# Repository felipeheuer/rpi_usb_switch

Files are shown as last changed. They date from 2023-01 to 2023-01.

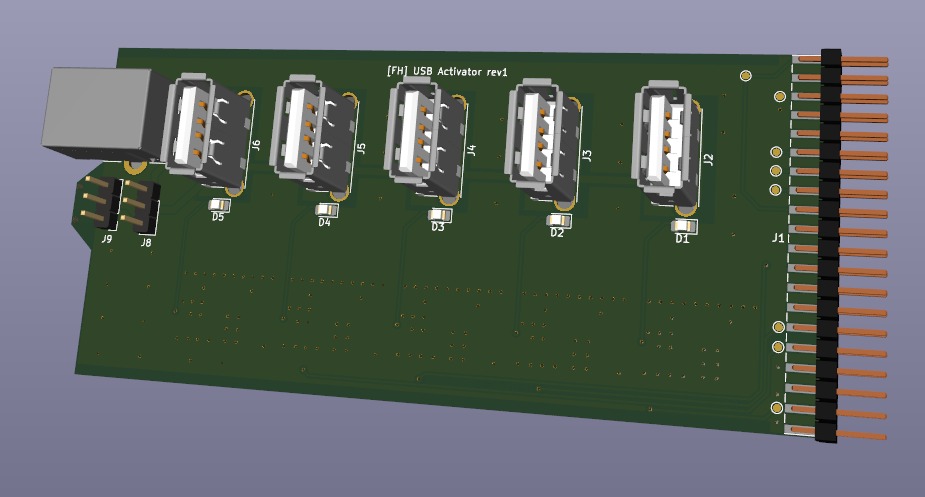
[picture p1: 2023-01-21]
img/board-rev1.jpeg

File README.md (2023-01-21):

# Raspberry Pi controlled USB switch

This is a simple project that allows you to enable/disable power lines from 5 USB ports individually over 5 GPIO's from a Raspberry Pi.

Was initially made to re-use an old dead USB hub that was laying down on my drawers an recycle it into a nice hub for powering up my LED gadgets.
The Mosfet circuitry layout is based on a generic circuit found on Amazon from different brands, but might have [this guy](https://michiel.vanderwulp.be/domotica/Modules/MosFetPwmDriveModule/) as a father.

**Data lines are disabled, this is only used for devices that have USB port as power source.**

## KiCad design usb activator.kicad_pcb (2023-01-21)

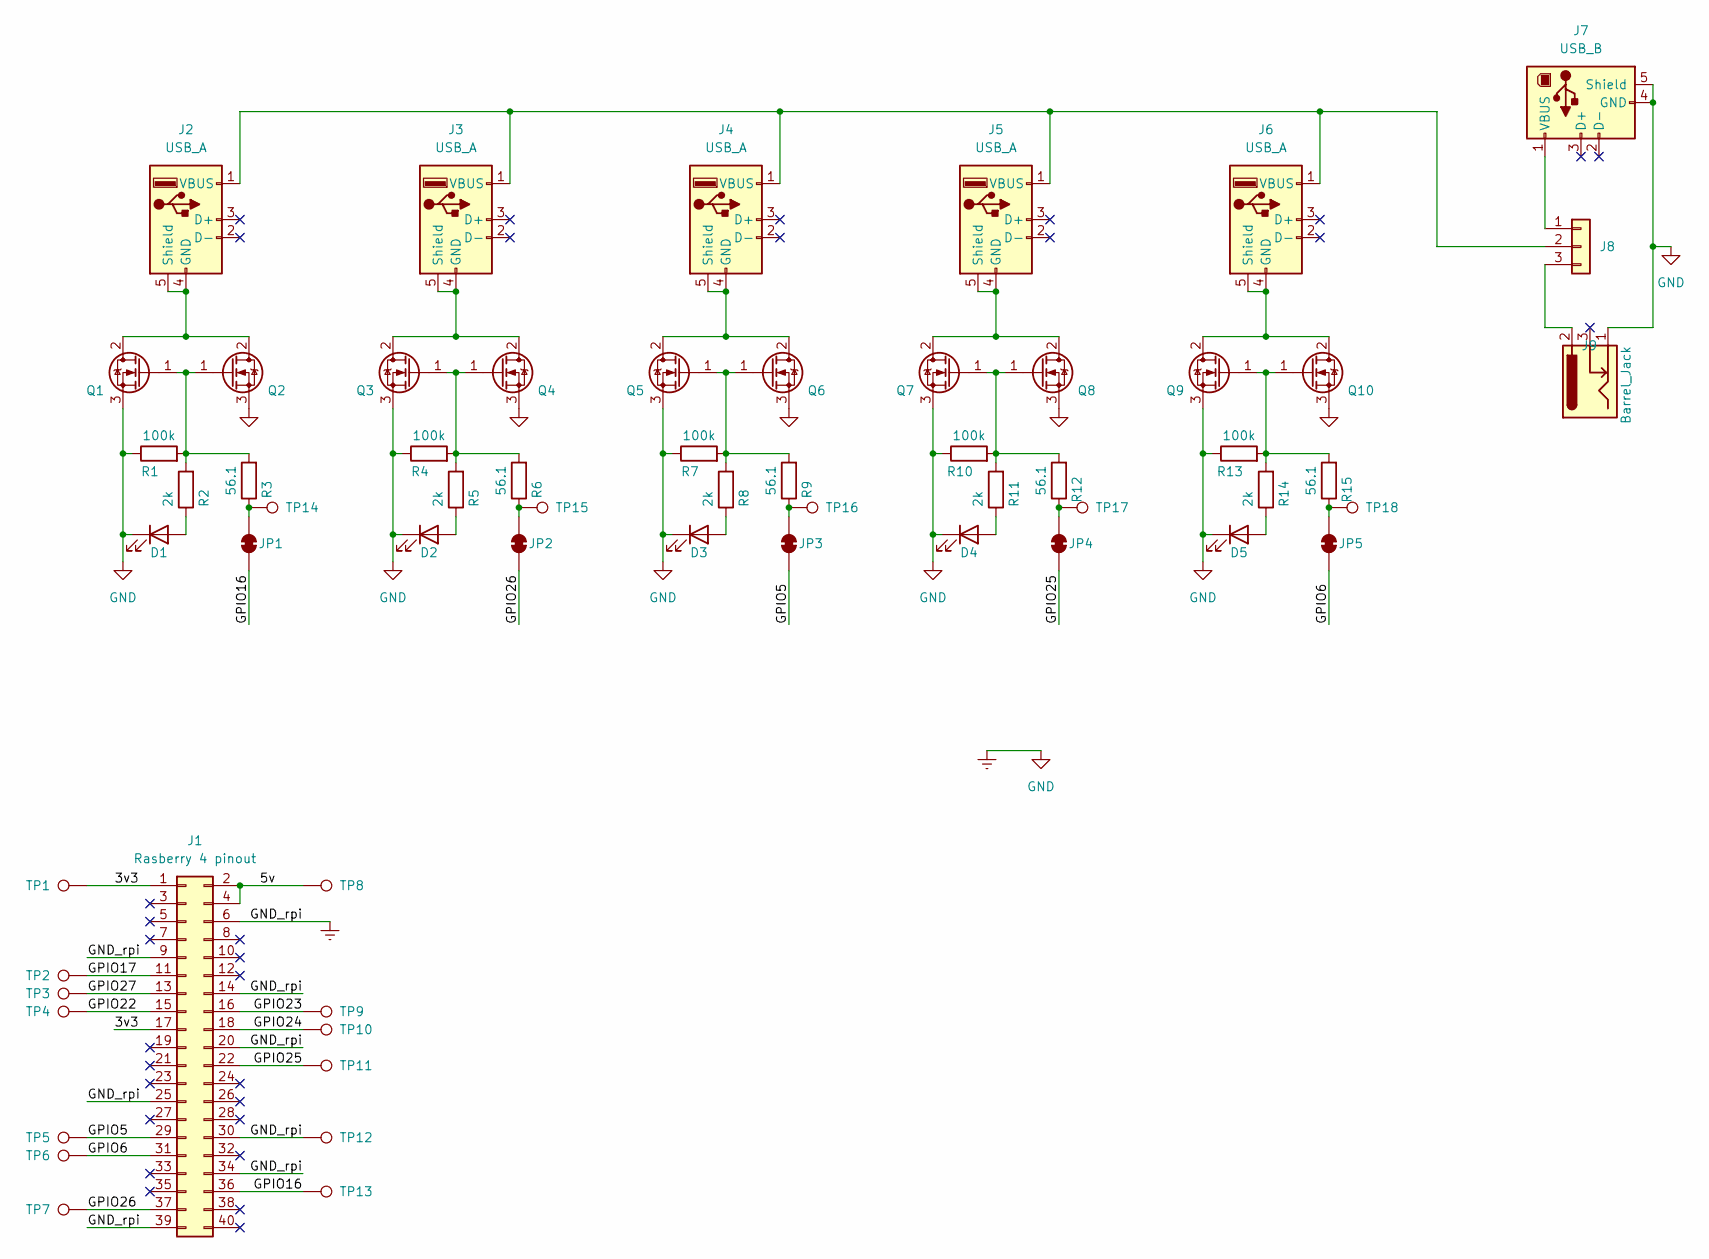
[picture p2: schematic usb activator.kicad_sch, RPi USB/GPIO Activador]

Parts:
D1, D2, D3, D4, D5: LED; LED_0805_2012Metric_Pad1.15x1.40mm_HandSolder
J1: Rasberry 4 pinout; Header_Board_Edge_2x20
J2, J3, J4, J5, J6: USB_A; USB_A_Generic_Vertical
J7: USB_B; USB_B_Lumberg_2411_02_Horizontal
J8: Conn_02x03_Counter_Clockwise; PinHeader_1x03_P2.54mm_Vertical
J9: Barrel_Jack; PinHeader_1x03_P2.54mm_Vertical
JP1, JP2, JP3, JP4, JP5: SolderJumper_2_Bridged; SolderJumper-2_P1.3mm_Bridged_RoundedPad1.0x1.5mm
Q1, Q2, Q3, Q4, Q5, Q6, Q7, Q8, Q9, Q10: IPD50R3K0CE; TO-252-2
R1, R4, R7, R10, R13: 100k; R_0805_2012Metric_Pad1.20x1.40mm_HandSolder
R2, R5, R8, R11, R14: 2k; R_0805_2012Metric_Pad1.20x1.40mm_HandSolder
R3, R6, R9, R12, R15: 56.1; R_0805_2012Metric_Pad1.20x1.40mm_HandSolder
TP1, TP2, TP3, TP4, TP5, TP6, TP7, TP8, TP9, TP10, TP11, TP12, TP13, TP14, TP15, TP16, TP17, TP18: TestPoint; TestPoint_Pad_D1.0mm

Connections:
/3v3: J1.1, J1.17, TP1.1
/5v: J1.2, J1.4, TP8.1
/GPIO5: J1.29, JP3.1 (A), TP5.1
/GPIO6: J1.31, JP5.1 (A), TP6.1
/GPIO16: J1.36, JP1.1 (A), TP13.1
/GPIO17: J1.11, TP2.1
/GPIO22: J1.15, TP4.1
/GPIO23: J1.16, TP9.1
/GPIO24: J1.18, TP10.1
/GPIO25: J1.22, JP4.1 (A), TP11.1
/GPIO26: J1.37, JP2.1 (A), TP7.1
/GPIO27: J1.13, TP3.1
GND: D1.1 (K), D2.1 (K), D3.1 (K), D4.1 (K), D5.1 (K), J1.6, J1.9, J1.14, J1.20, J1.25, J1.30, J1.34, J1.39, J7.4 (GND), J7.5 (Shield), J9.1, Q1.3 (S), Q2.3 (S), Q3.3 (S), Q4.3 (S), Q5.3 (S), Q6.3 (S), Q7.3 (S), Q8.3 (S), Q9.3 (S), Q10.3 (S), R1.1, R4.1, R7.1, R10.1, R13.1, TP12.1
unnamed: D1.2 (A), R2.1
unnamed: D2.2 (A), R5.1
unnamed: D3.2 (A), R8.1
unnamed: D4.2 (A), R11.1
unnamed: D5.2 (A), R14.1
unnamed: J2.1 (VBUS), J3.1 (VBUS), J4.1 (VBUS), J5.1 (VBUS), J6.1 (VBUS), J8.2
unnamed: J2.4 (GND), J2.5 (Shield), Q1.2 (D), Q2.2 (D)
unnamed: J3.4 (GND), J3.5 (Shield), Q3.2 (D), Q4.2 (D)
unnamed: J4.4 (GND), J4.5 (Shield), Q5.2 (D), Q6.2 (D)
unnamed: J5.4 (GND), J5.5 (Shield), Q7.2 (D), Q8.2 (D)
unnamed: J6.4 (GND), J6.5 (Shield), Q9.2 (D), Q10.2 (D)
unnamed: J7.1 (VBUS), J8.1
unnamed: J8.3, J9.2
unnamed: JP1.2 (B), R3.1, TP14.1
unnamed: JP2.2 (B), R6.1, TP15.1
unnamed: JP3.2 (B), R9.1, TP16.1
unnamed: JP4.2 (B), R12.1, TP17.1
unnamed: JP5.2 (B), R15.1, TP18.1
unnamed: Q1.1 (G), Q2.1 (G), R1.2, R2.2, R3.2
unnamed: Q3.1 (G), Q4.1 (G), R4.2, R5.2, R6.2
unnamed: Q5.1 (G), Q6.1 (G), R7.2, R8.2, R9.2
unnamed: Q7.1 (G), Q8.1 (G), R10.2, R11.2, R12.2
unnamed: Q9.1 (G), Q10.1 (G), R13.2, R14.2, R15.2

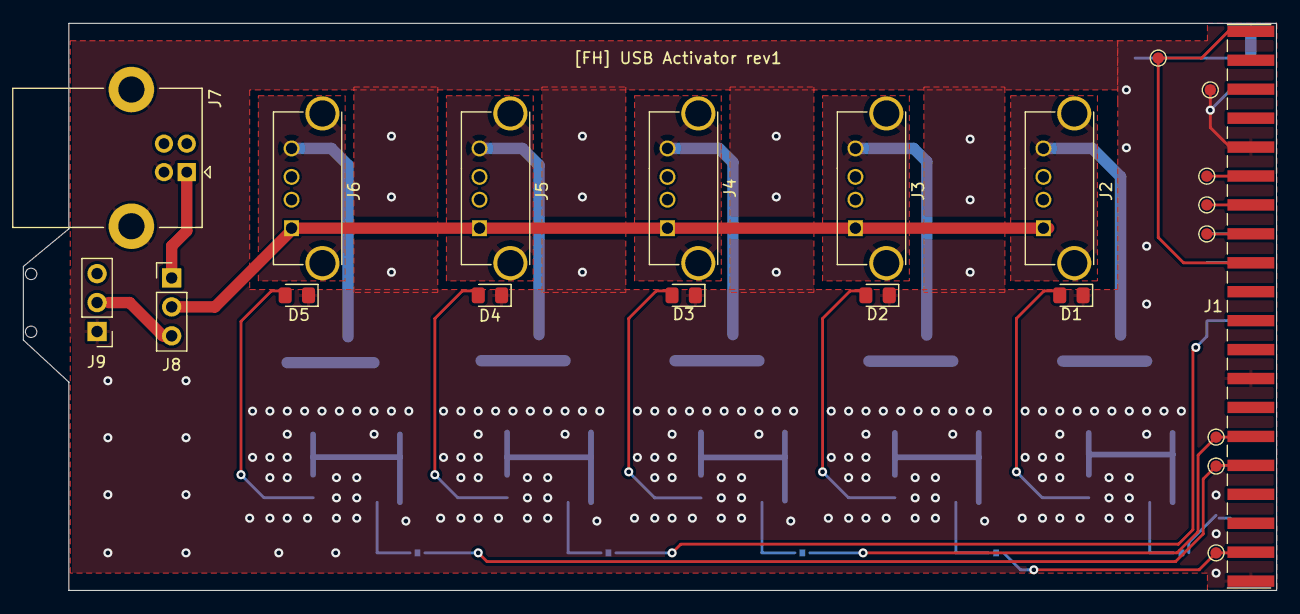
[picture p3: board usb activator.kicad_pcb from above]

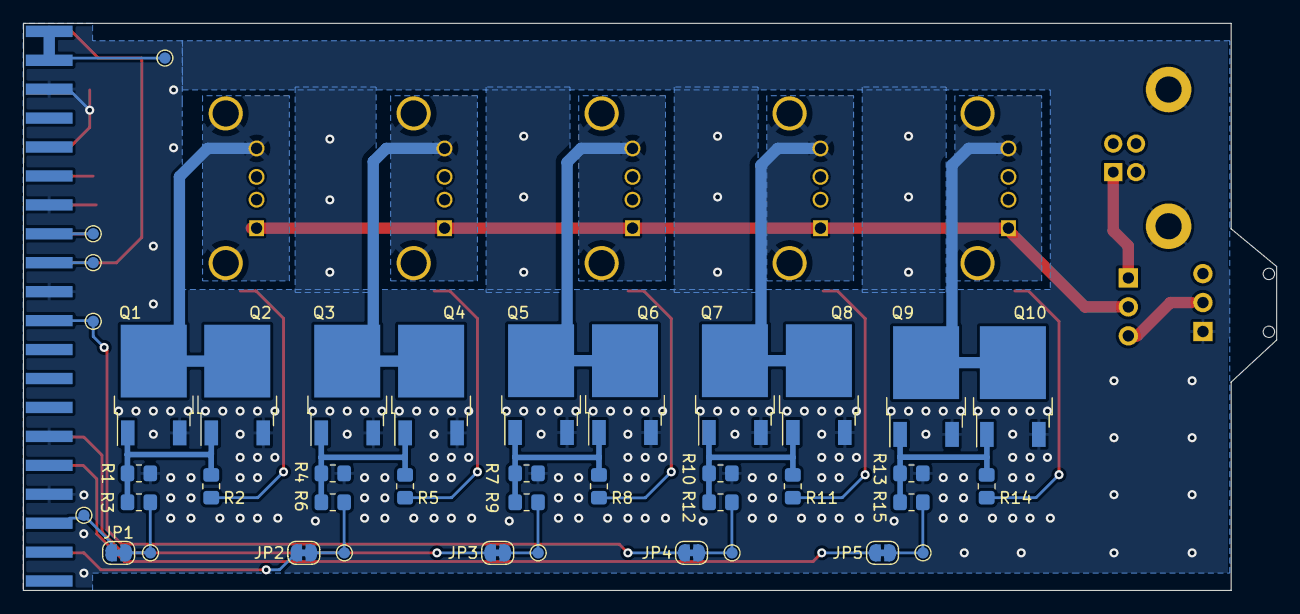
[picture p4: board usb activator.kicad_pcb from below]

Board: 2 copper layers, 110.0 x 49.8 mm, 62 parts (40 on the bottom side), 36 nets.
